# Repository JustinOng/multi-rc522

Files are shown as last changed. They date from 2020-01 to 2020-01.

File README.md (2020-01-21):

PCB designed to control 6x RC522 RFID readers from a ESP32.

It has been observed that certain RC522 modules sourced from China come populated with a clone/counterfeit MFRC522. These readers appear to operate fine alone (other than a different version ID of `0x12`), but data corruption occurs when multiple RC522 modules are connected on the same SPI bus (my theory is that the negating the SS pins do not fully isolate the readers from the bus).

As such, this project connects all 6 readers together, treating all 6 as a single device (ie sharing `SCK`, `MOSI`, `MISO` and `SS` pins), then asserting all the RST pins of the modules and releasing one at a time for communication.

## Issues with Rev 1:

* G12 of the ESP32 is connected to RST5. This is problematic because the pin is pulled HIGH from the RC522 modules, preventing the ESP32 from booting from flash. Connecting RST5 to G15 is a workaround:
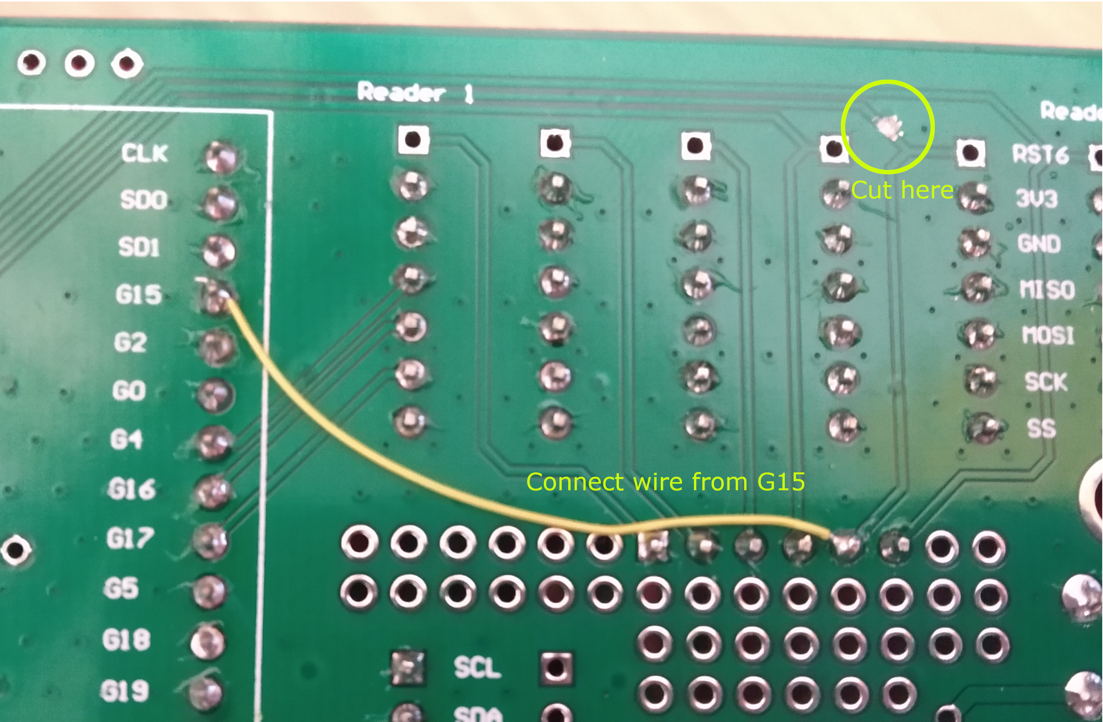
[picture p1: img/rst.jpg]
PCB Modification
  

* The silk screen for the keypad is inverted, the correct pins have been labelled below:
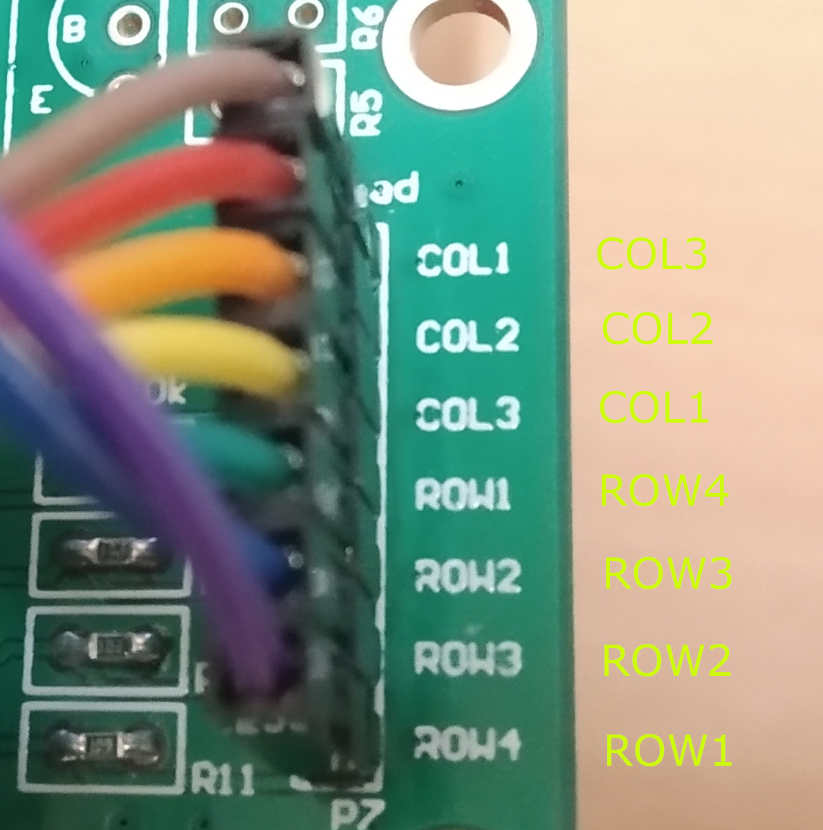
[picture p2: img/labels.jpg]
Keypad


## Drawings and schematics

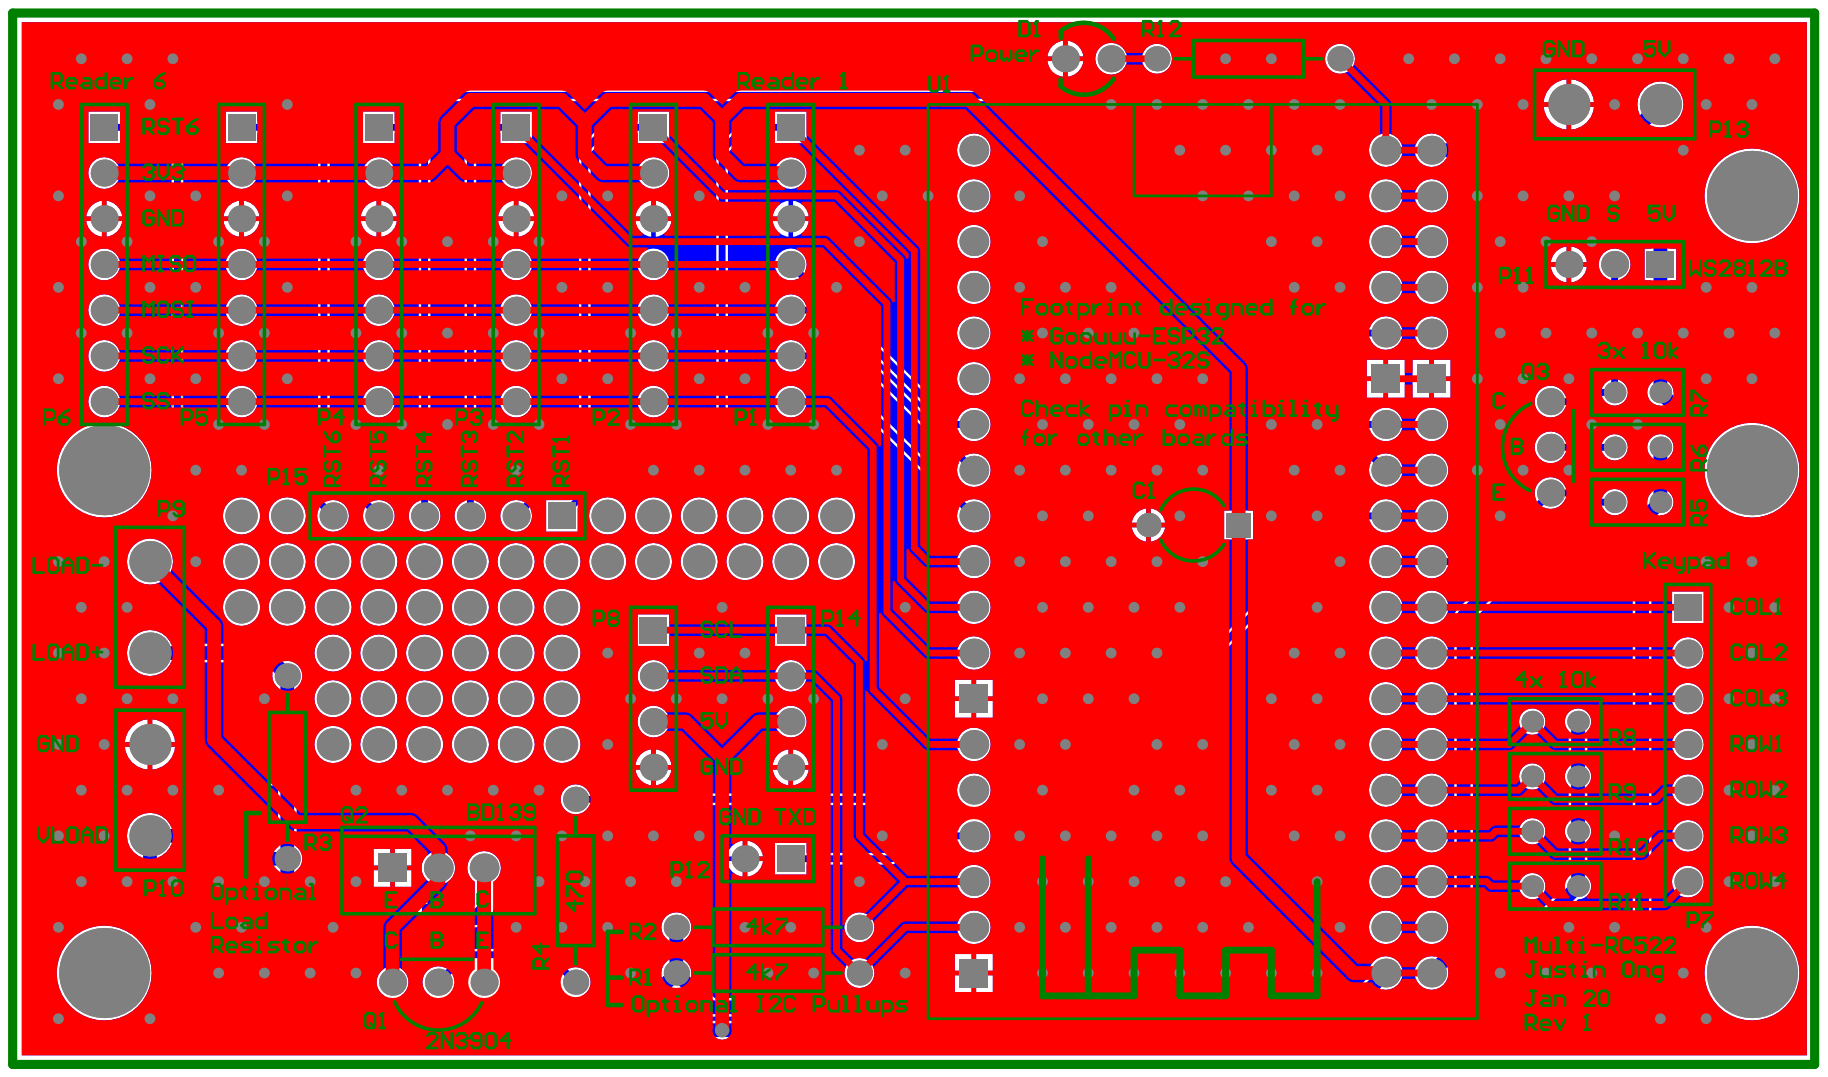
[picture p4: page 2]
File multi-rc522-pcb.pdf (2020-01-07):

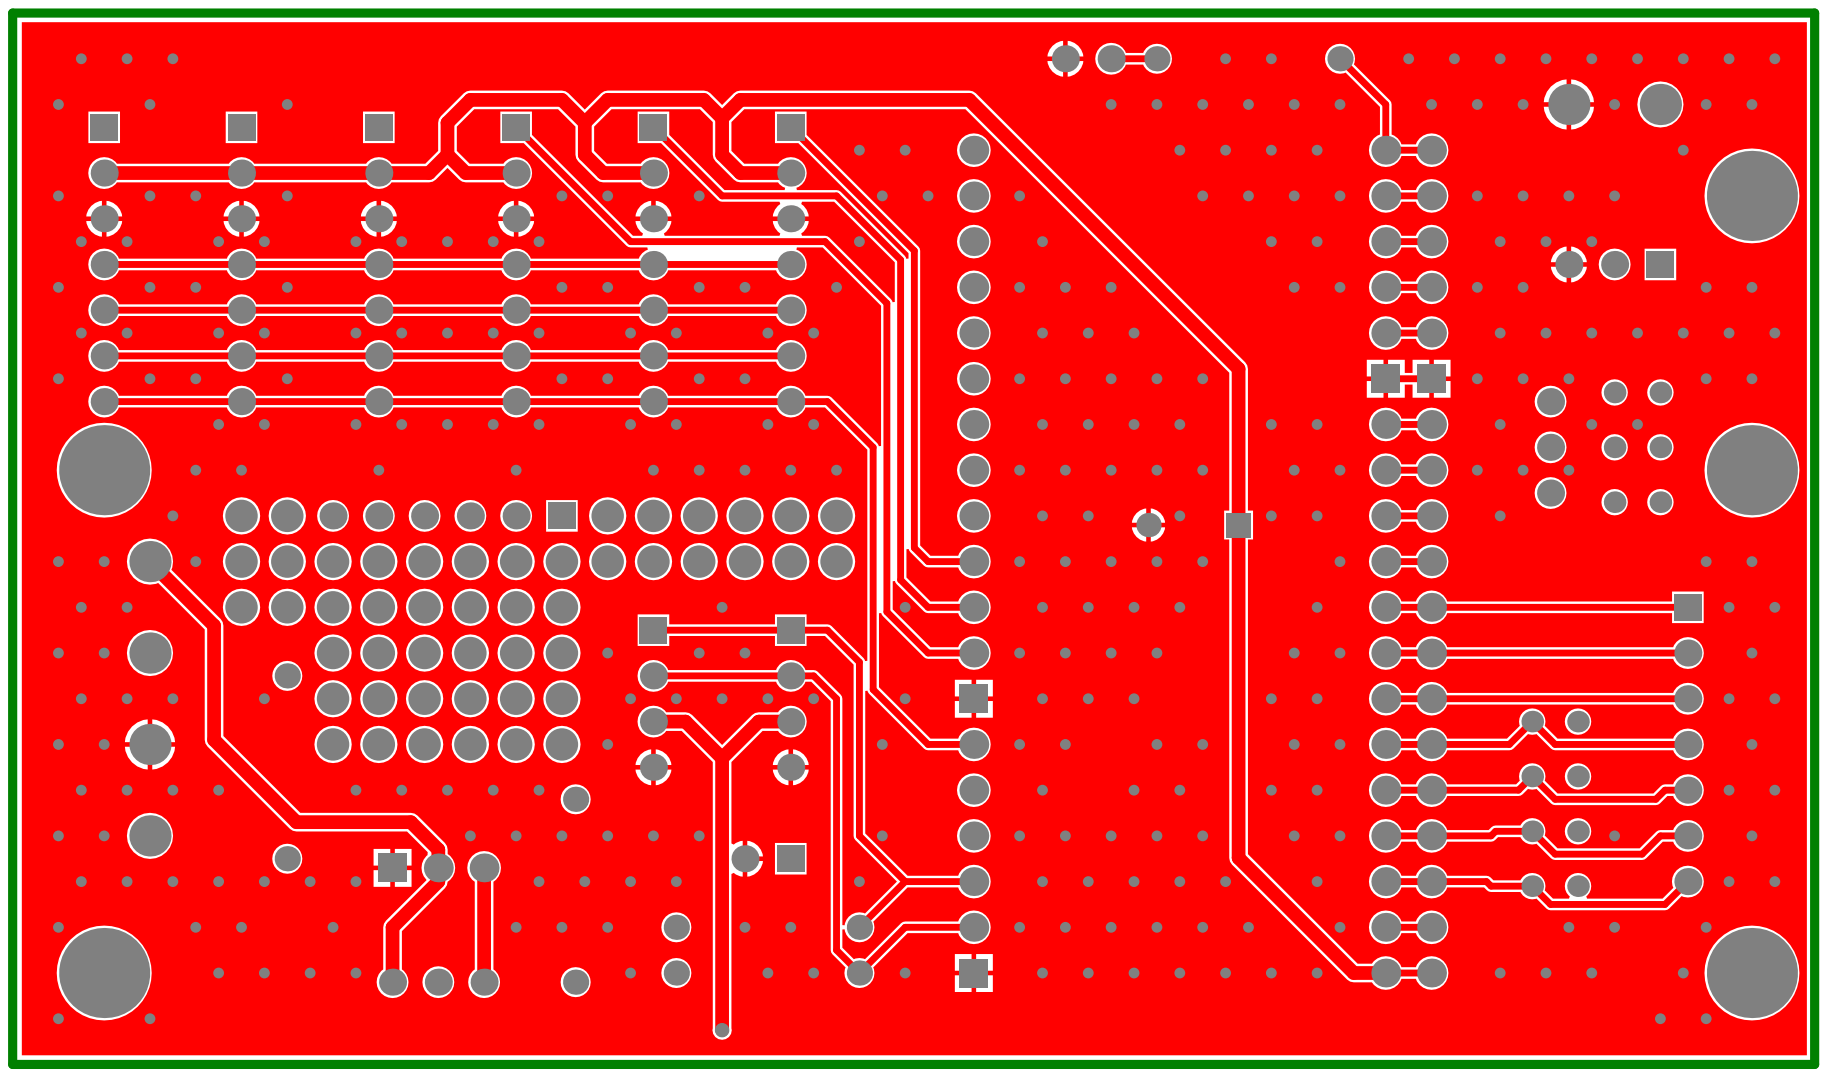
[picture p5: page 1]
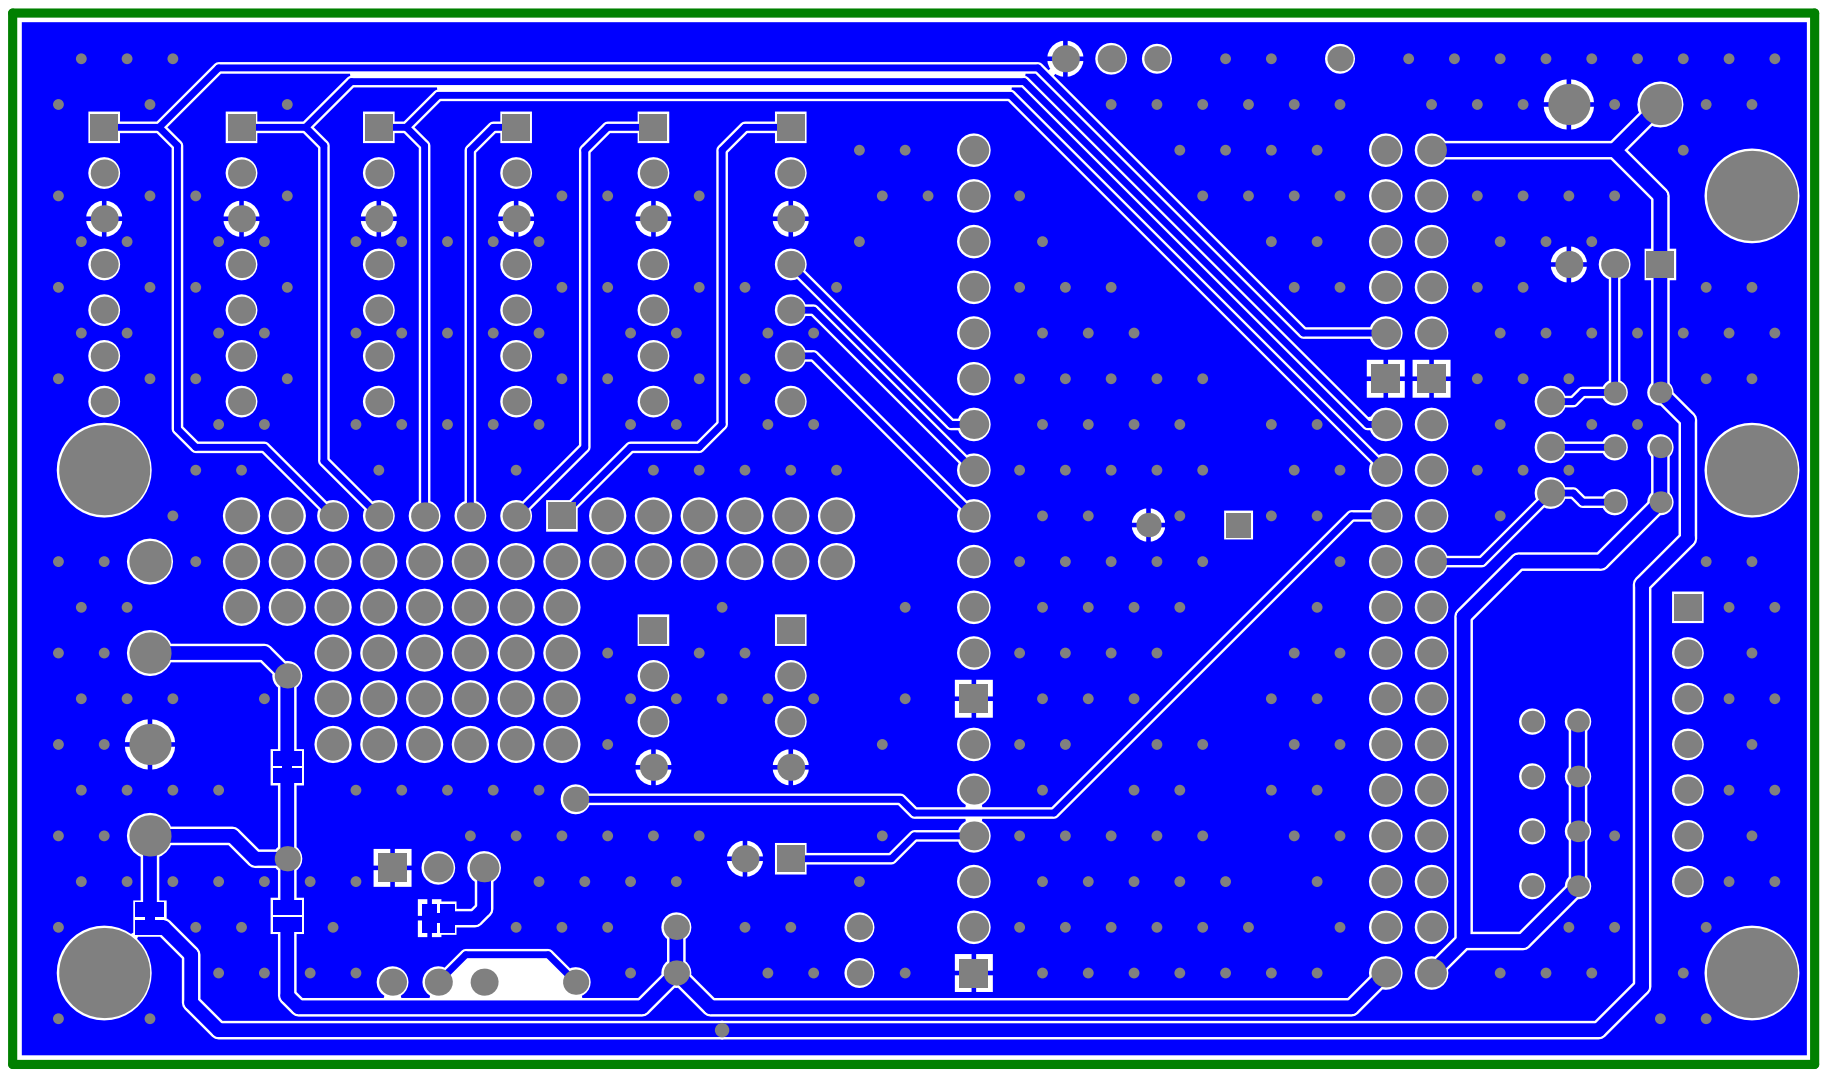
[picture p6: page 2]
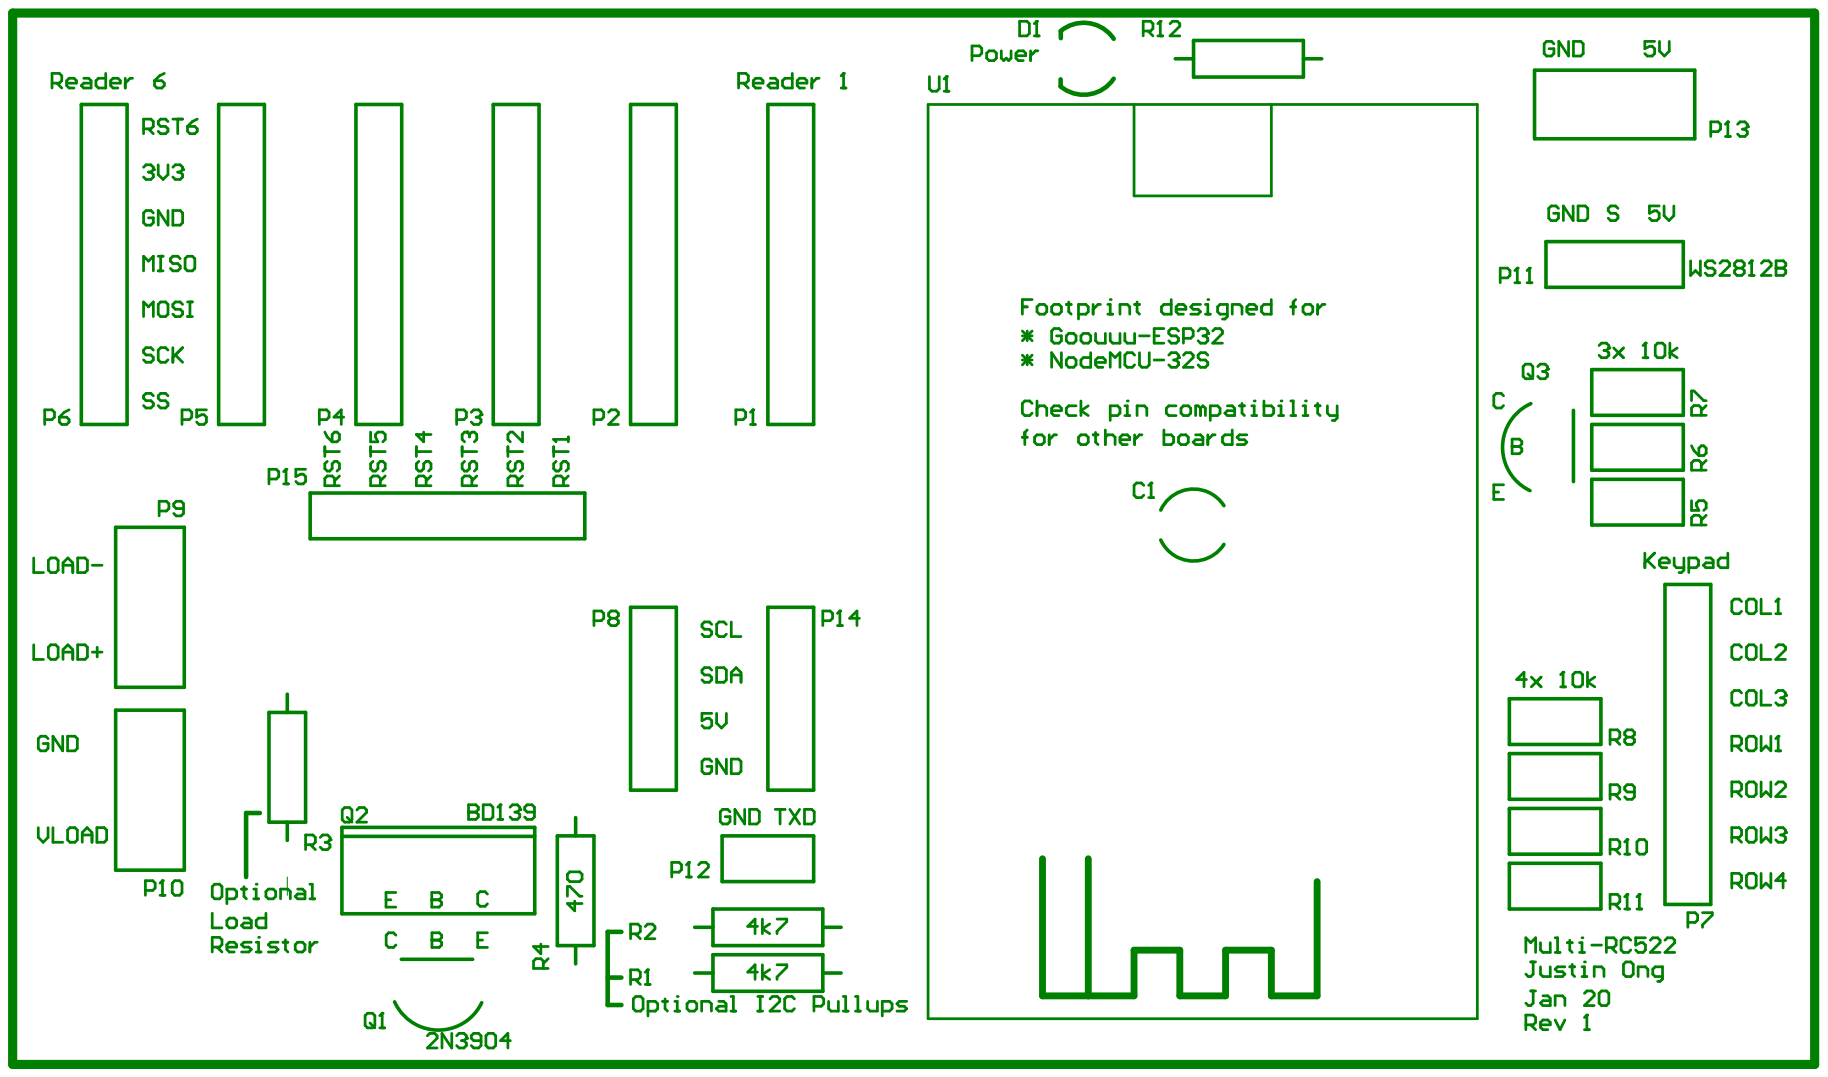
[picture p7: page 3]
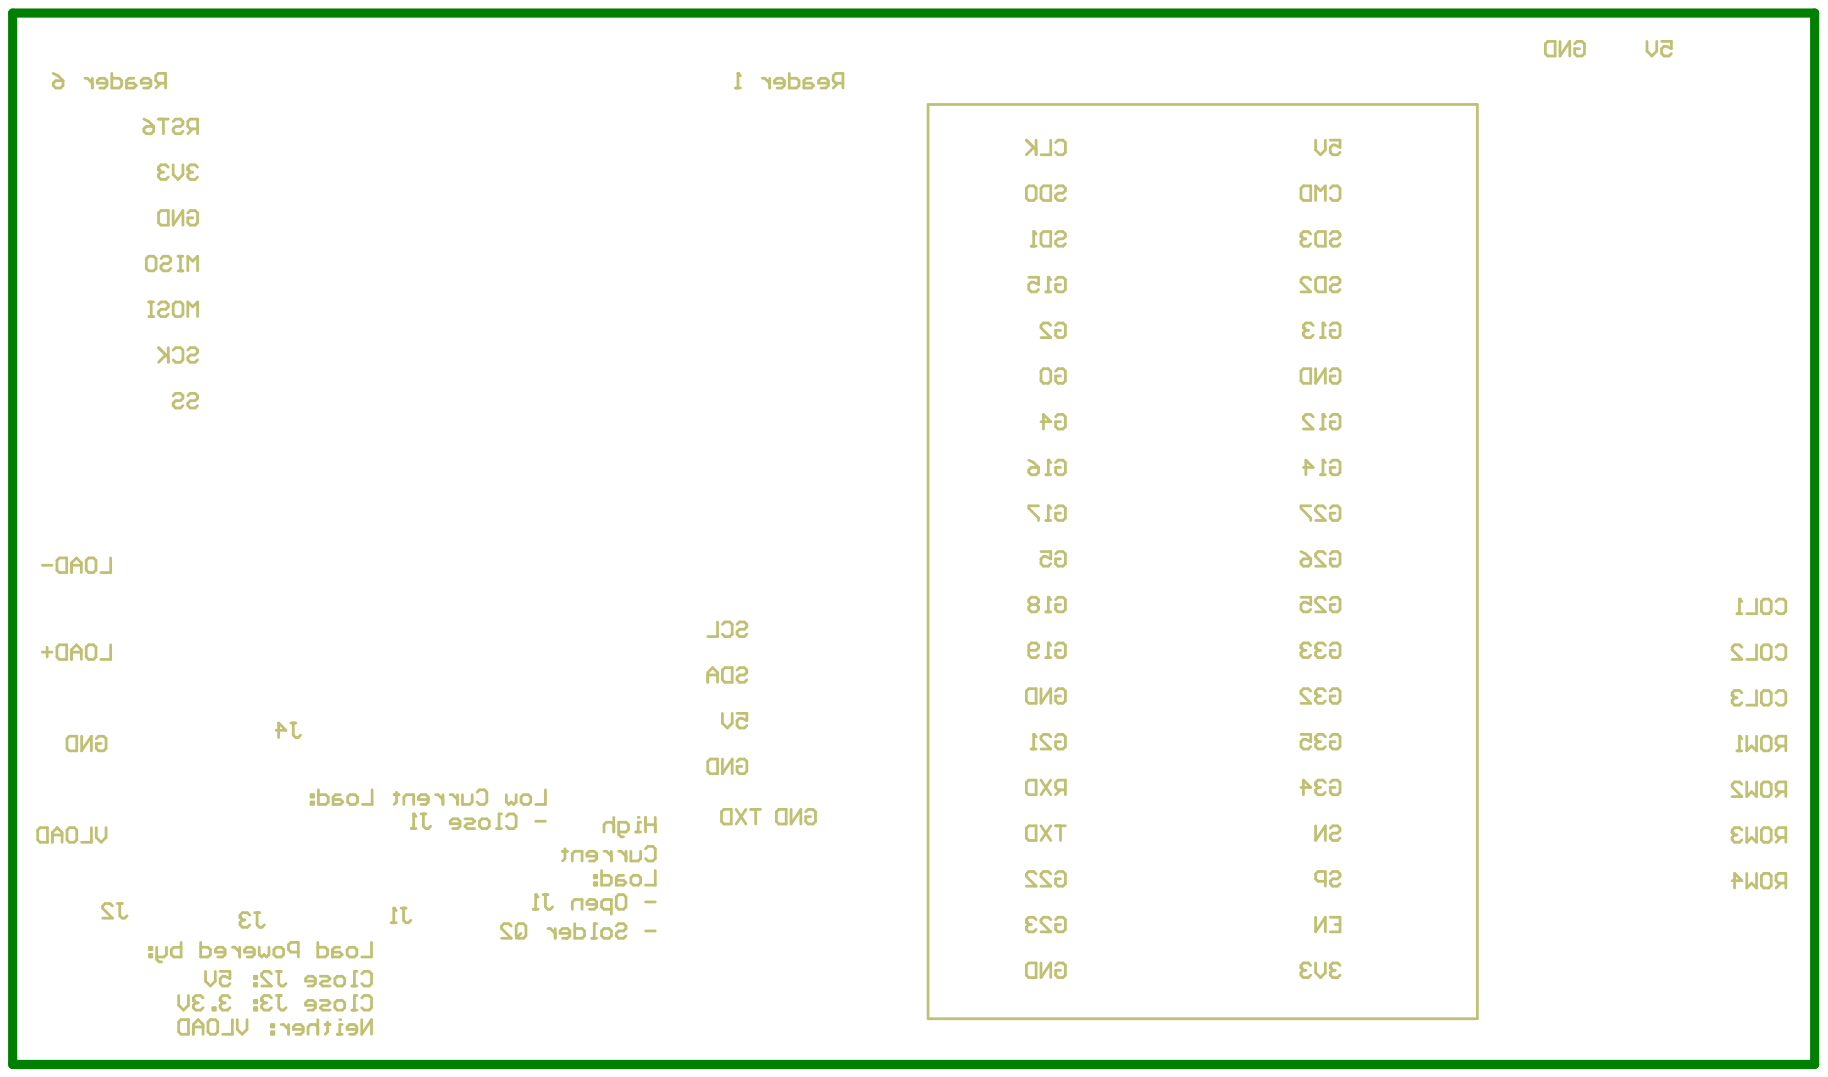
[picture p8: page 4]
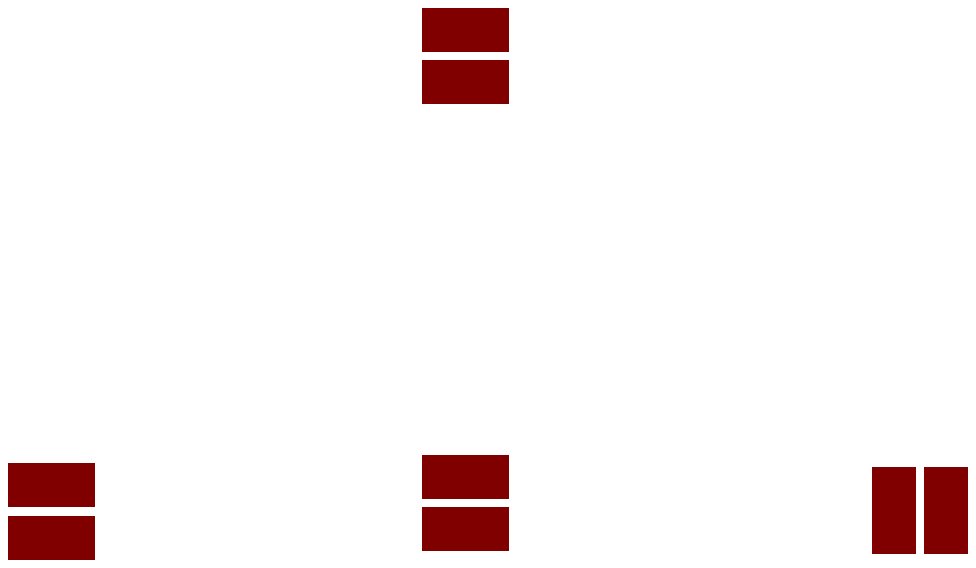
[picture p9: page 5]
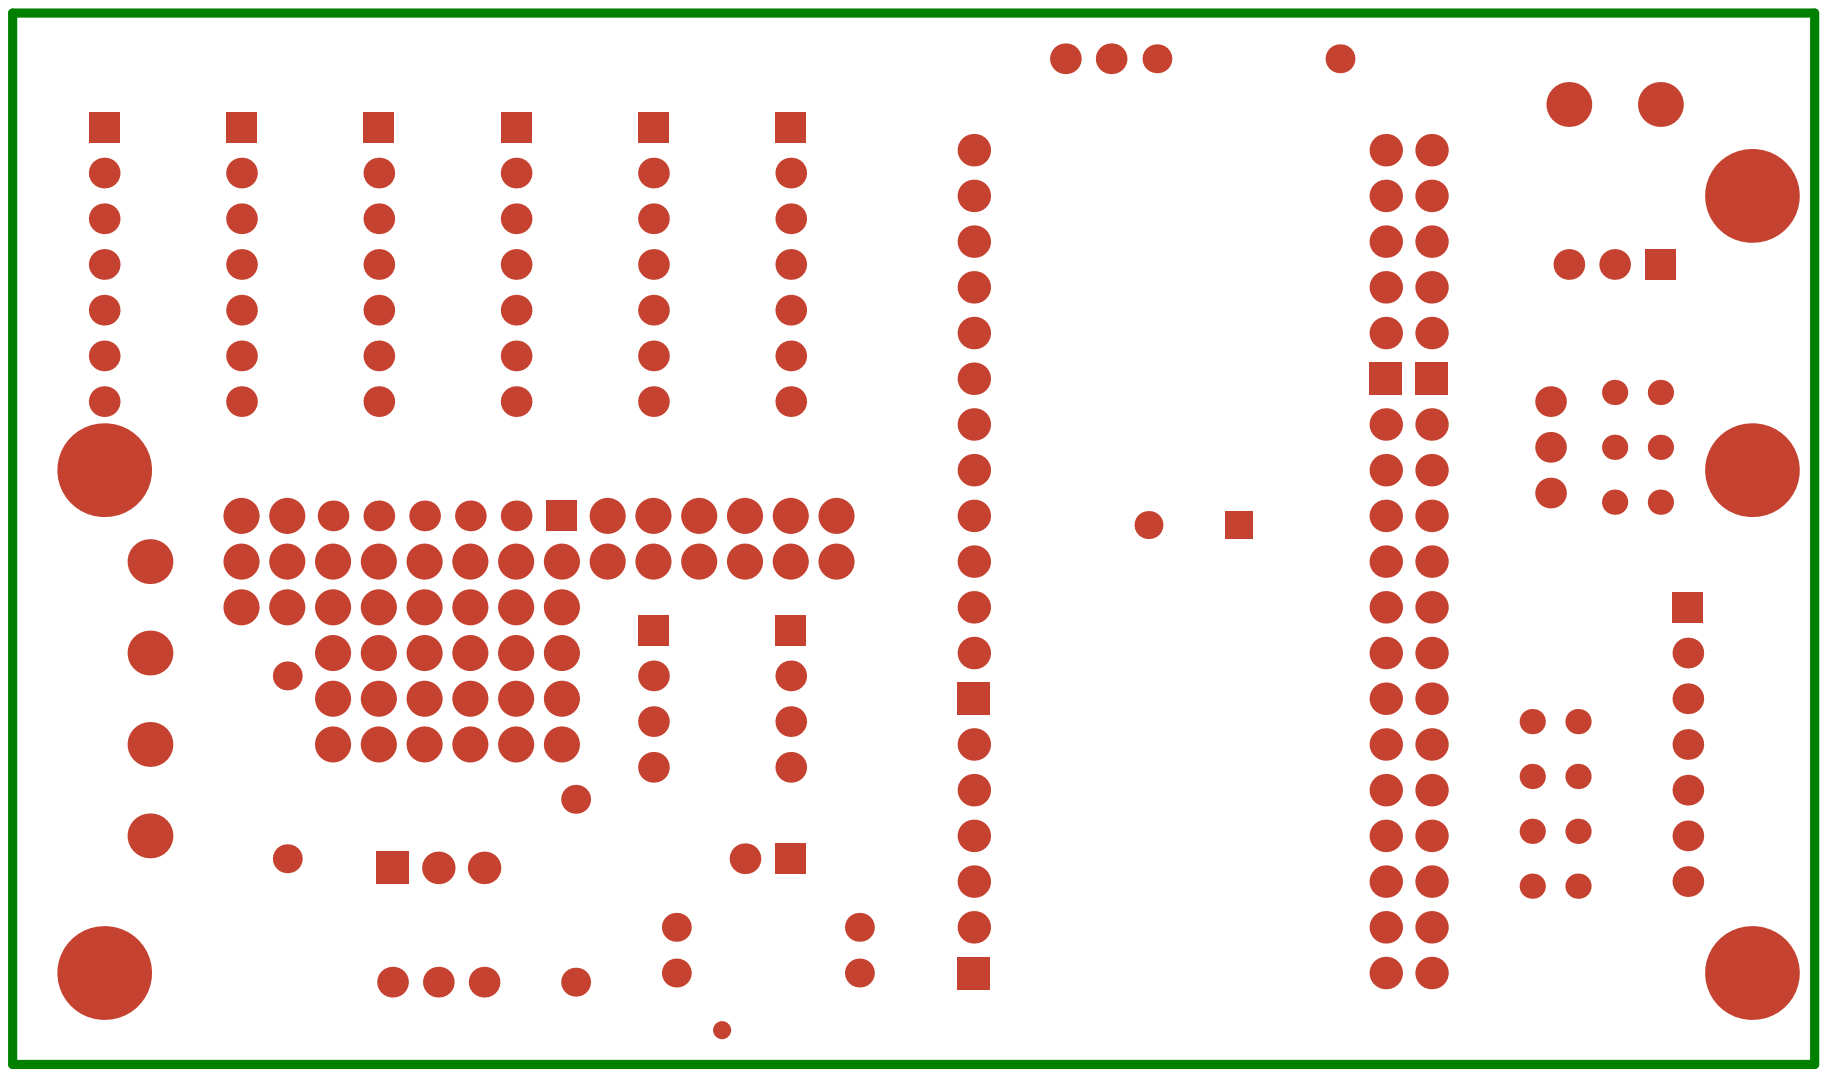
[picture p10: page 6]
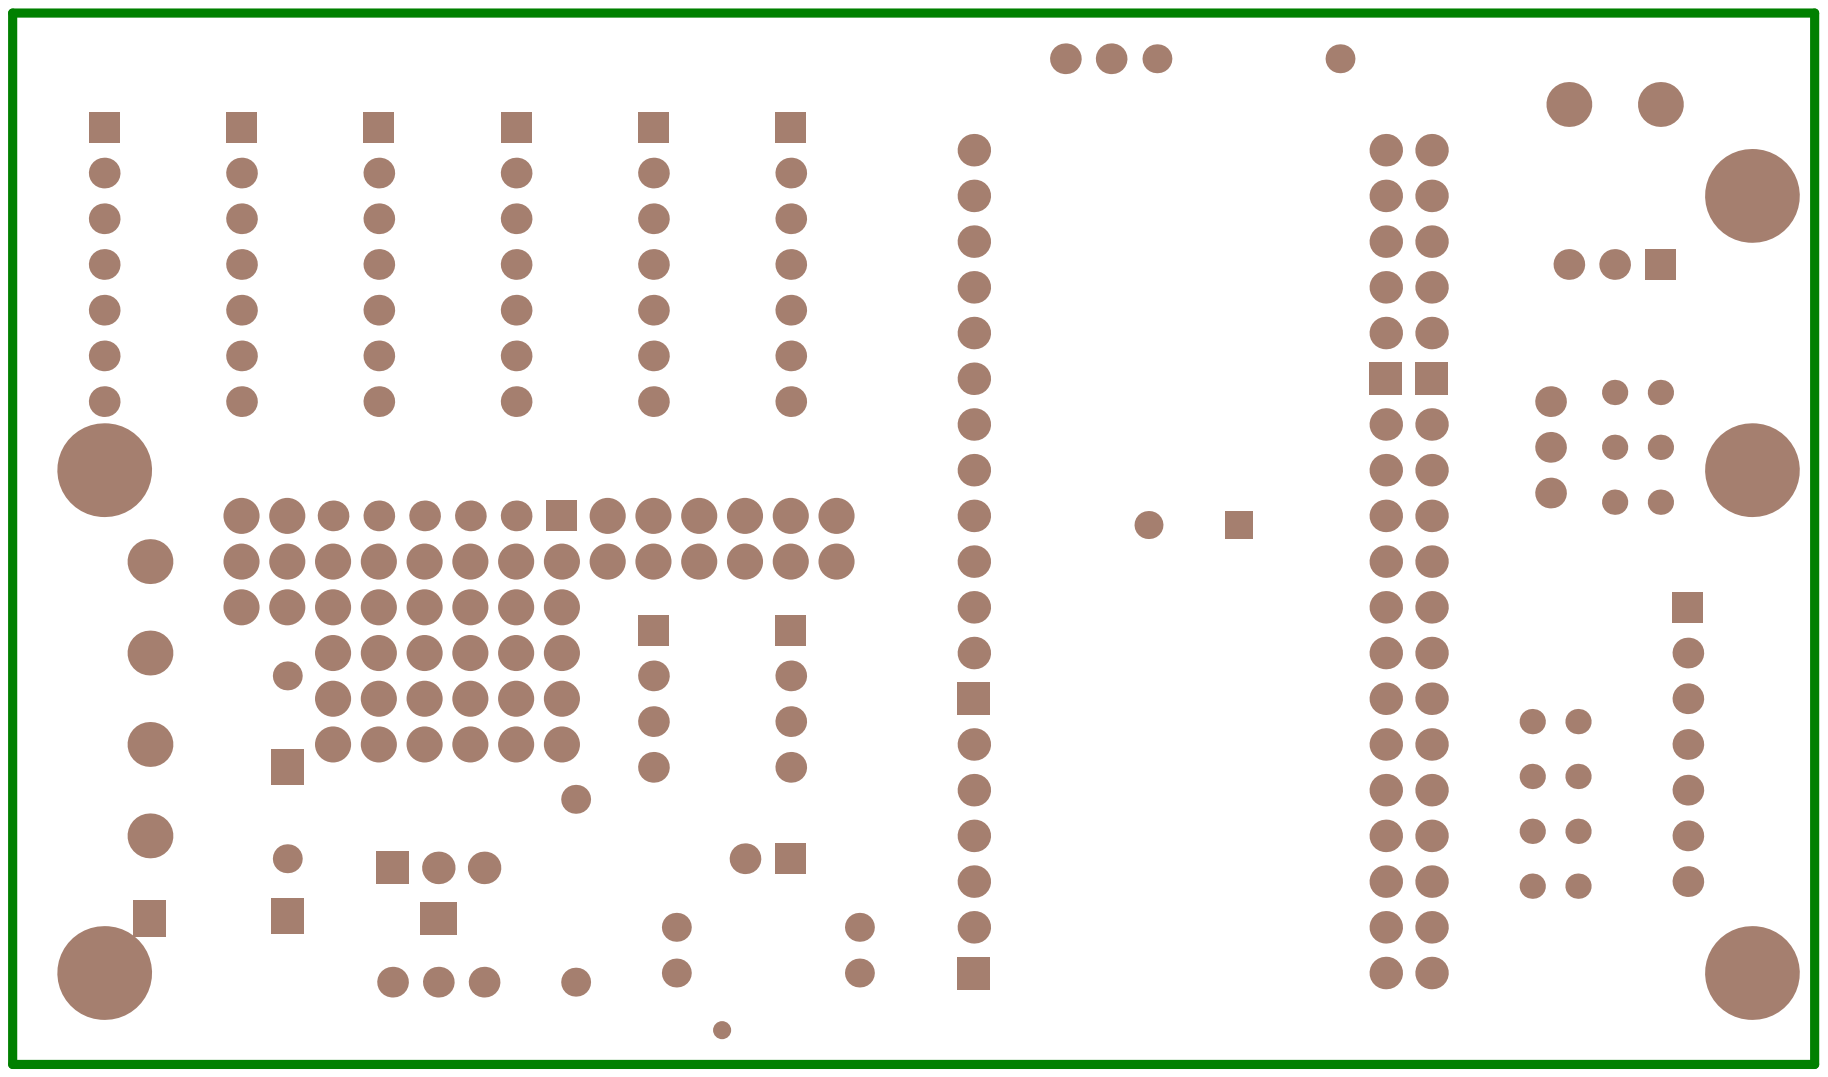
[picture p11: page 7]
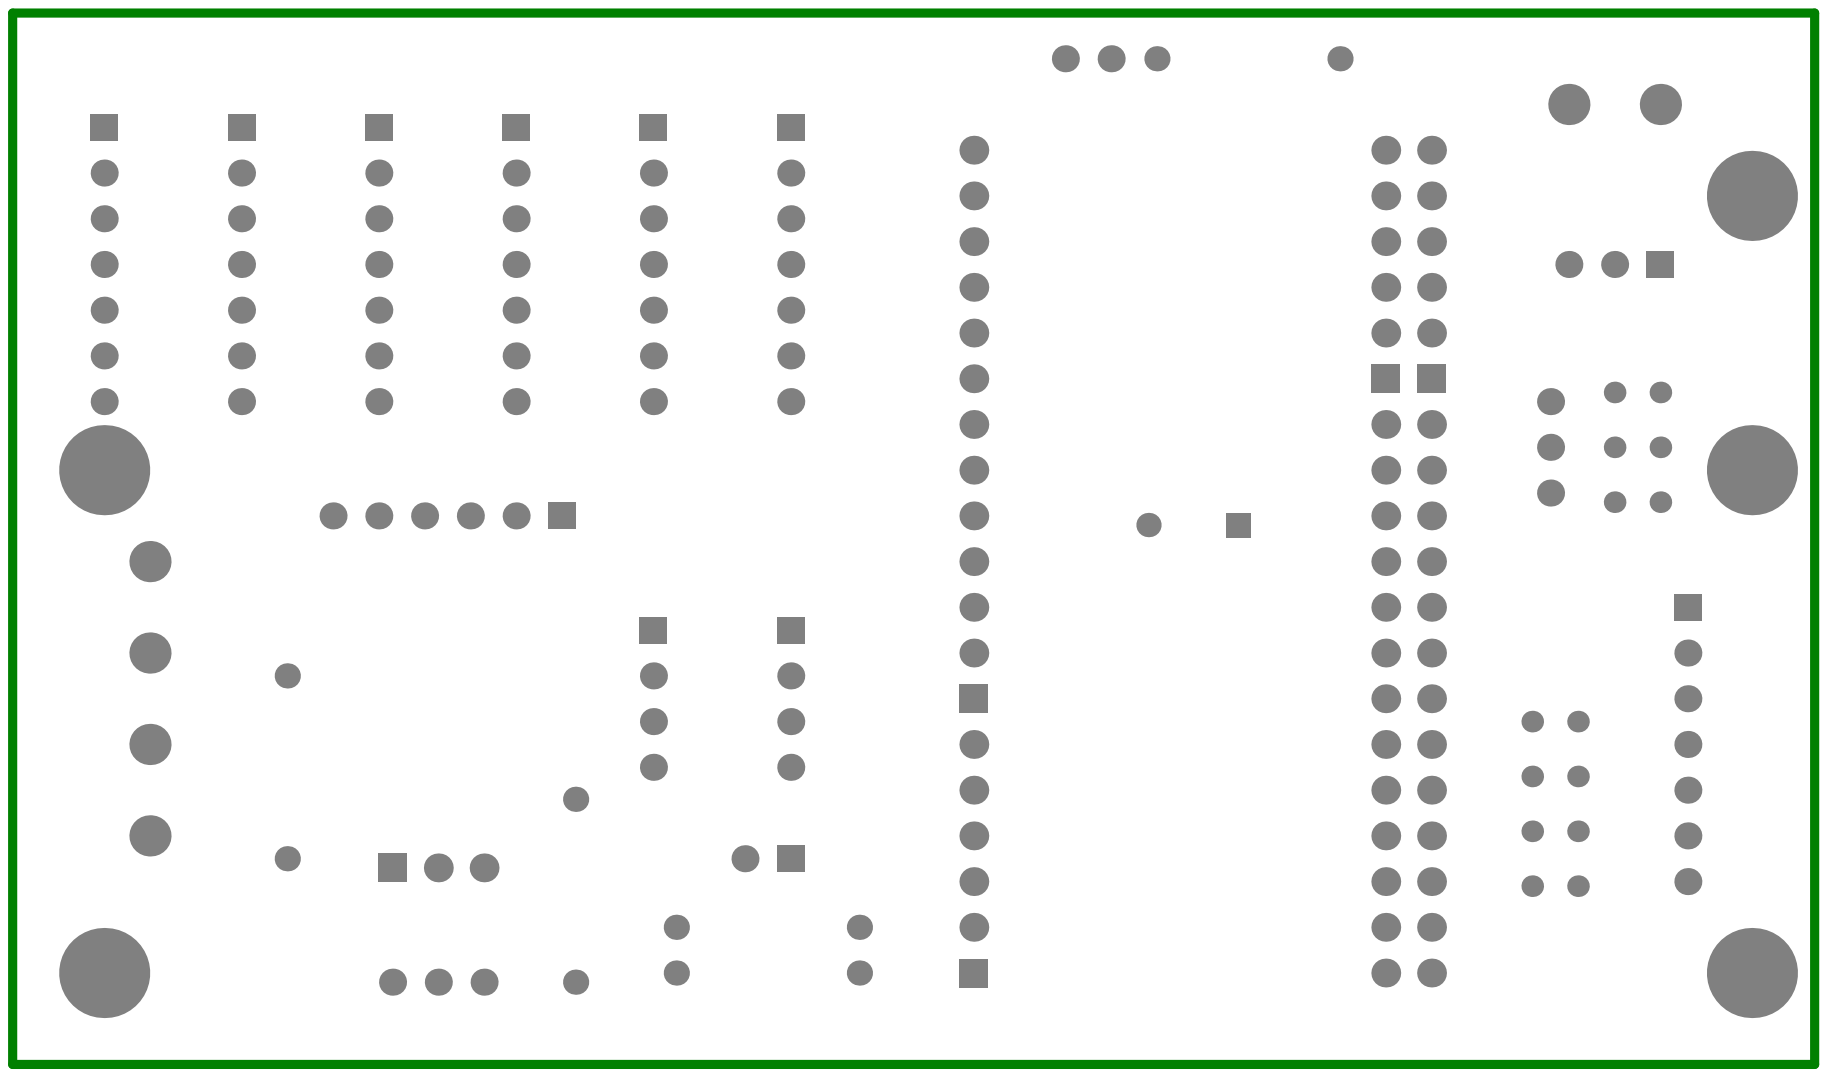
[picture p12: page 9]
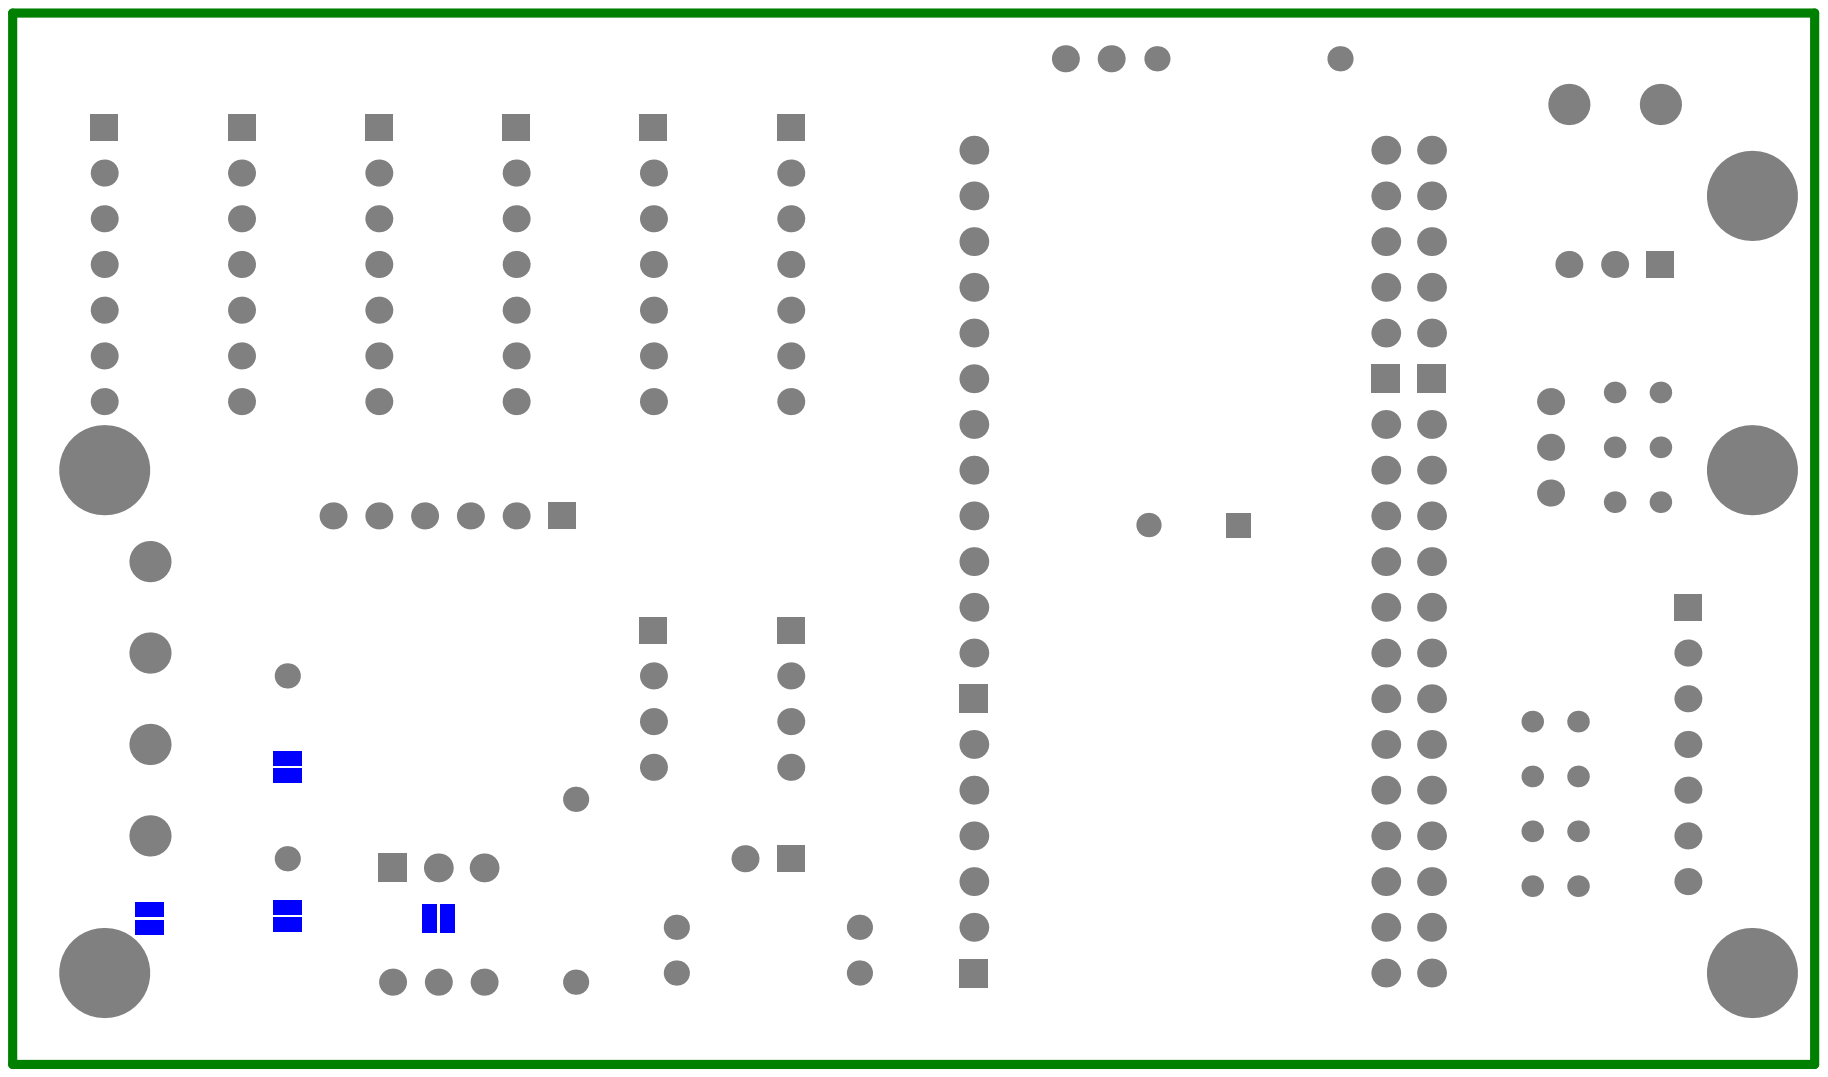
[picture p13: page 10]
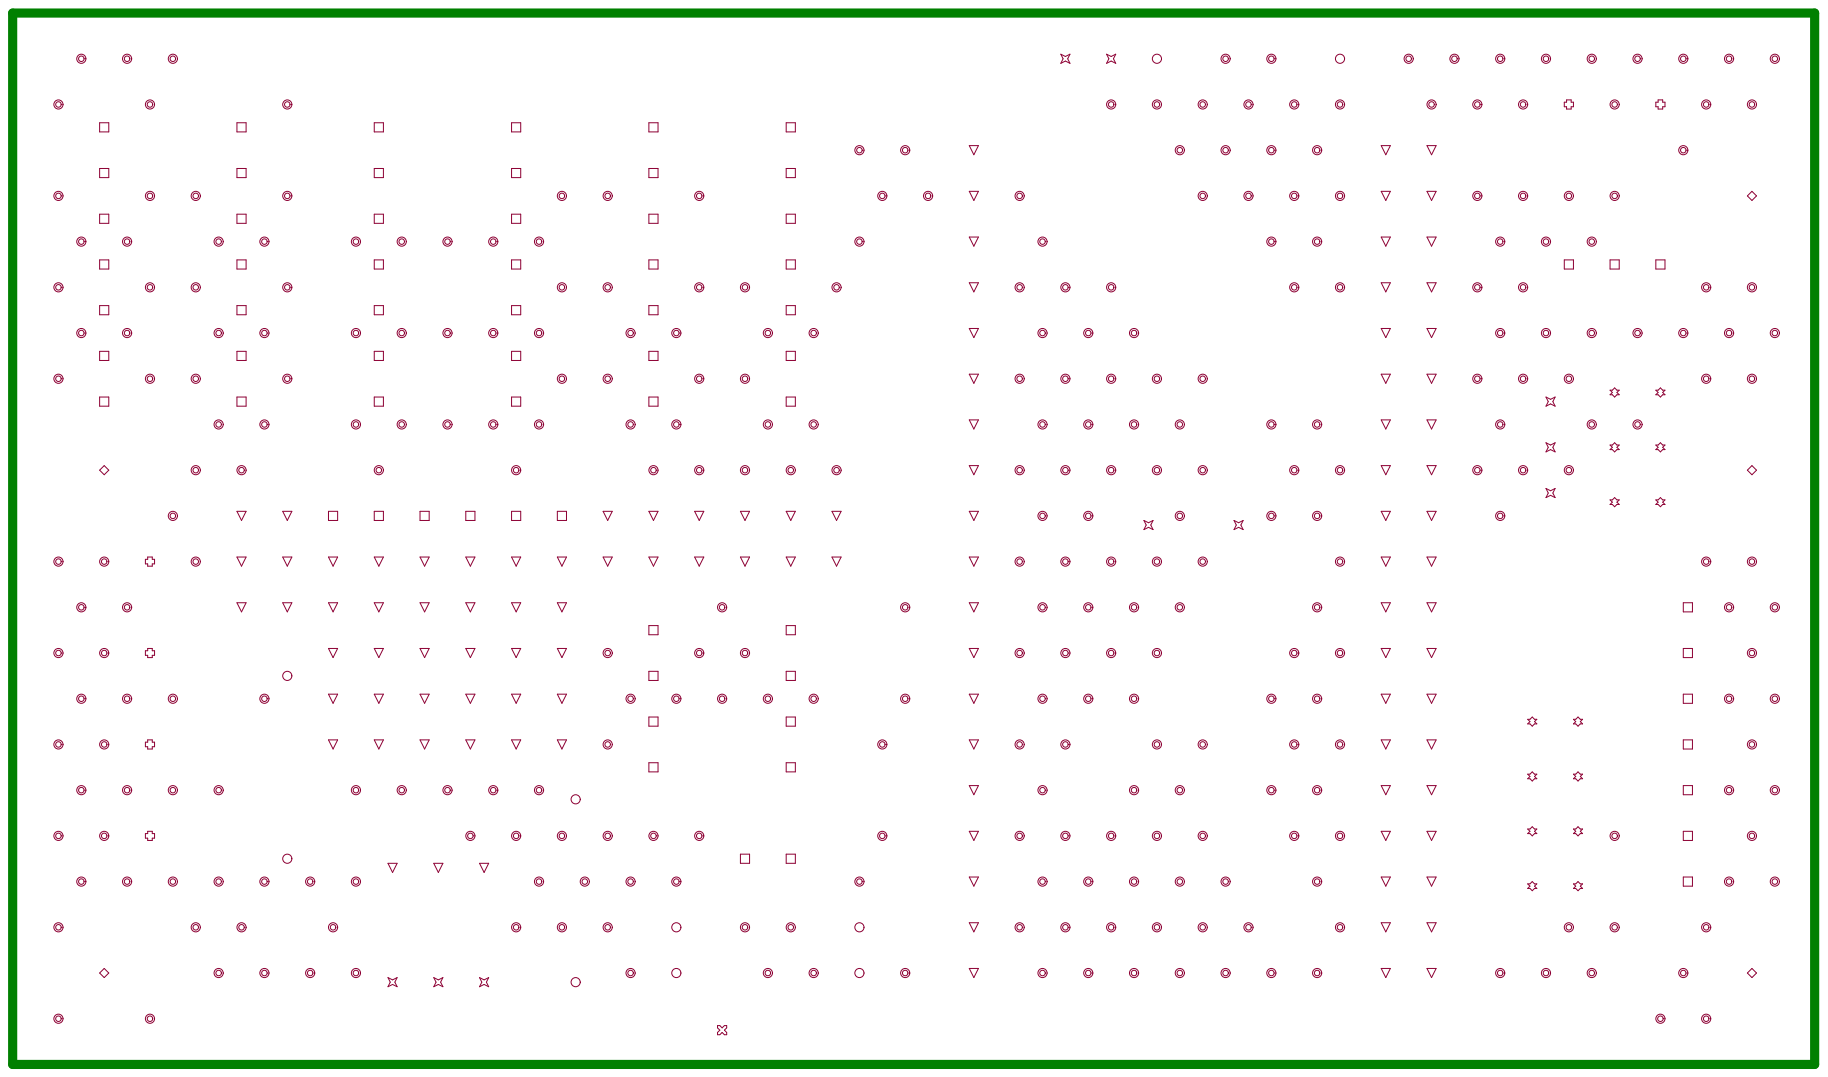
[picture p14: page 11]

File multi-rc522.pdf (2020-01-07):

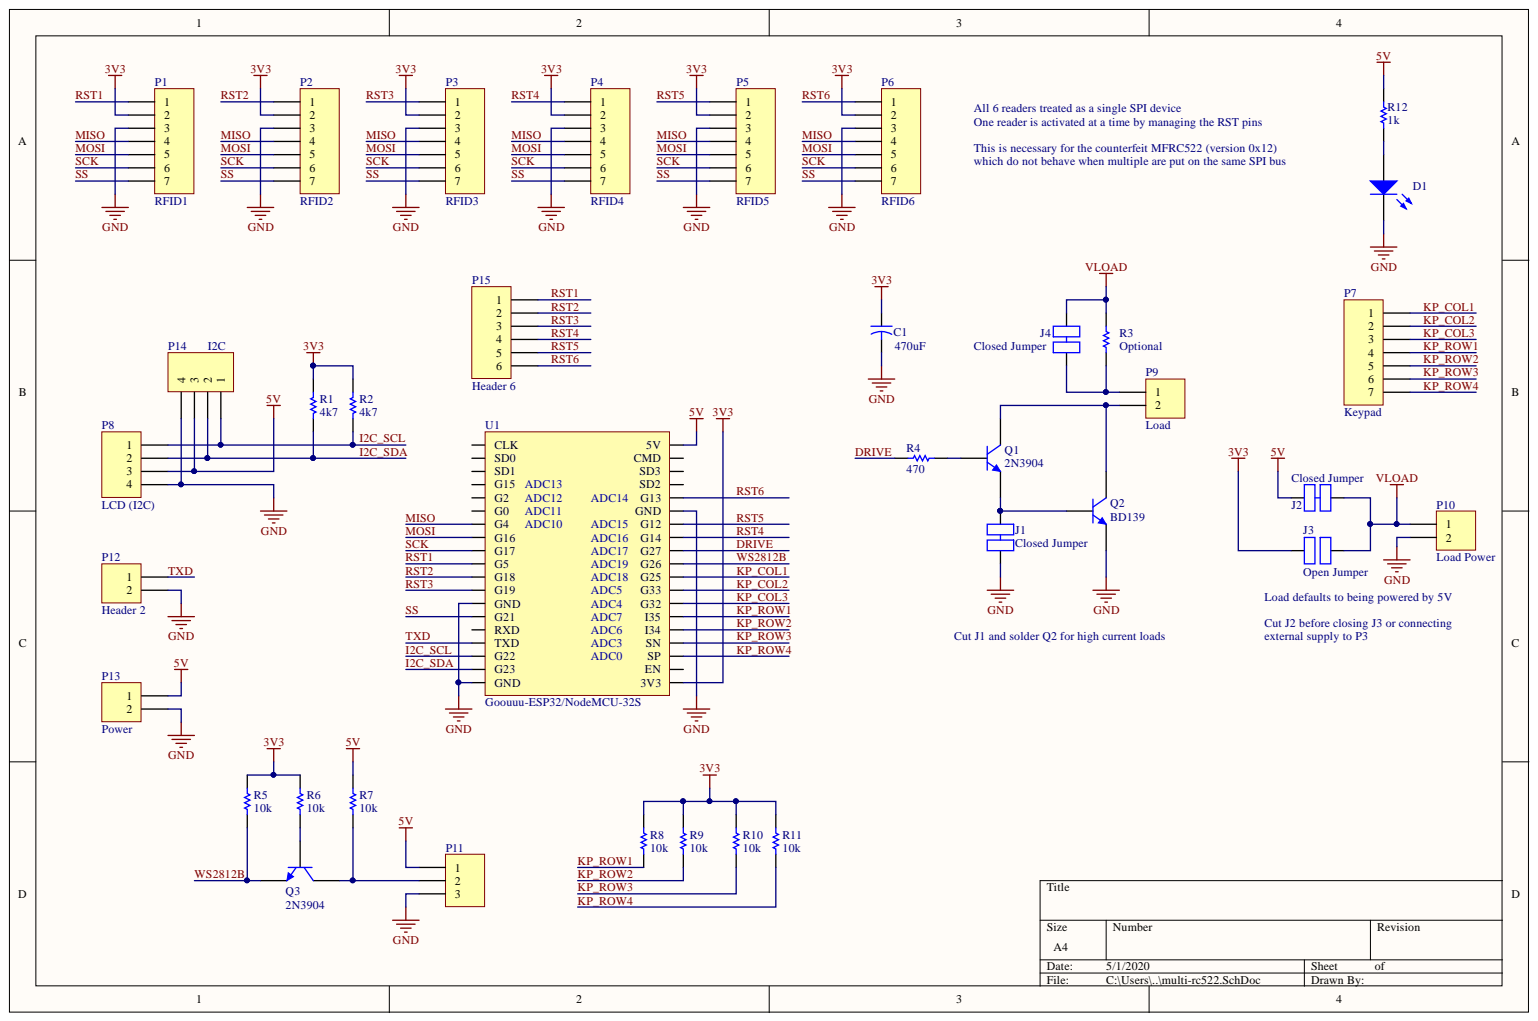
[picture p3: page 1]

All 6 readers treated as a single SPI device
One reader is activated at a time by managing the RST pins

This is necessary for the counterfeit MFRC522 (version 0x12)
which do not behave when multiple are put on the same SPI bus

Load defaults to being powered by 5V

Cut J1 and solder Q2 for high current loads

Cut J2 before closing J3 or connecting
external supply to P3
